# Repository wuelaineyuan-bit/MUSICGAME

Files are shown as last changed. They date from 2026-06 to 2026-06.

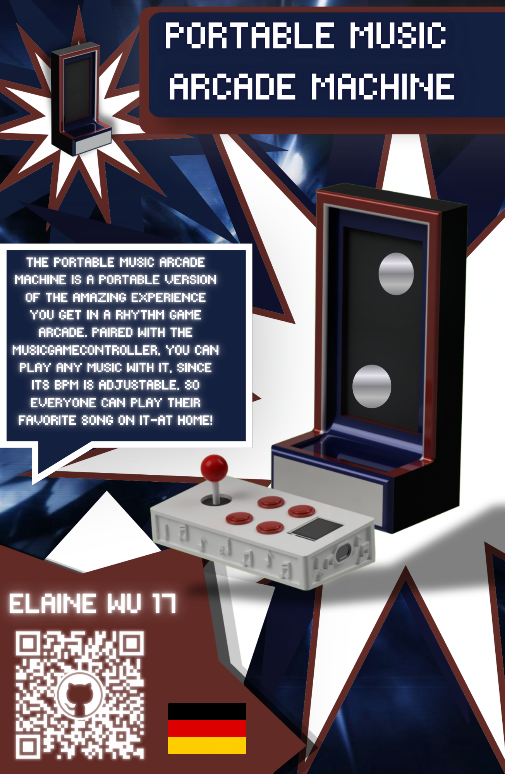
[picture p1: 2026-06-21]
zine.png

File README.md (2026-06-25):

# ARCADE-MUSICGAME
 # Zine
 zine

# Description
The music game arcade is a portable version of the amazing experience you get in a rhythm game arcade. Combined with the Music-Game-Controller, you can play any music with it, since its BPM is adjustable, so everyone can play their favorite song on it-AT HOME!

The controller itself was designed seperately in another sub project.

Musicgame-Controller: https://github.com/Gnoled5660/Musicgame-Controller
# Game Concept
Since this is my first hardware project ever, I wanted the concept to be as simple as possible, I do have quite some of software experience though. The LED Matrix as display shows two tiles (L and R) dropping down, similarly to Piano Tiles. Using the Musicgame-Controller, the player can press L, R or both at the same time in order to hit the notes. 
You can adjust BPM and the amount of beats. The higher the BPM, the harder it will be to hit the notes at the right time. The higher the amount of beats, the longer the session will be. You could even double the amount of beats if you want to play your song on loop multiple times. You need to search up the BPM and find the beatamount for your song separately.
There are four different feedbacks you can get: miss, good, great and perfect. In ascending order, they give you a higher score. The game outputs the percentage of right moves you did and also a score. Your goal is to hit the highest percentage/score. Have fun!
# Motivation
I have always loved going to music arcades. They are colorful, fun and beautiful. Most importantly, I love rhythm games. This is why I wanted to make a rhythm game with the display being an arcade controller. Originally, my idea was to use slippers as the buttons. However after my friend showed me a design, I immediately thought that the arcade controller would be alot cooler and more fitting to the theme.
There is one problem. I live in Germany and there is not a single music game arcade that I can go to and have fun with my friends. Another problem that I found was that you cant particularly choose your music. You always have to hope for songs that you like to appear magically.
With this portable music arcade game I want to bring everyone who owns it the joy of arcade games at home. Everyone in Germany, anyone in any country. And no more gambling with songs as well. Since BPM and beat amount are adjustable, you can simply search up the bpm and beat amount of your song and start playing any song, no matter how niche it might be. 
I hope this little device can light up the mood of anyone who feels a little down, just like music arcade lit me up with joy. 

# Schematic
The schematic is rather simple. The LED Matrix is powered by a Meanwell LRS-50-5, which delivers 5V and up to 10A, which is enough for the display. The Pico 2 can either be powered by the Meanwell or be connected to the computer. The only thing that is important is, that the computer needs to be connected to the Pico 2, to send over the data. However, it is also connected to the powersupply. For this reason, the Meannwell is connected to the VSYS pin of the Pico 2, with a shottkey diode in between. The Meanwell is connected to a power outlet with a cable.

Bildschirmfoto 2026-06-21 um 00 57 17

# Firmware
The Firmware was first written as normal computer program in c++, with the intention of implementing it into hardware later on. So before that, the Windows library-included command GetAsyncKeyState was used to sense input. The software itself counts the beats using the included chrono library in c++.
The software itself uses the amount of beats(beatamount), the beats per minute(bpm) and the count of the last beat (lastBeat) for the metronome/time-counting system to work and four vectors are used for the rhythm game judging system to work. 

The time-counting system works through a loop that will only run while the actual number of beats in the system is smaller than beatamount. A timestamp is also made at the start(start) of the program. This timestamp(start) is constantly getting compared to the timestamp that is created newly everytime the loop starts a new time (new). These two timestamps are used to create a duration called ms (now-start). Ms is getting compared to lastBeat as well as the amount of ms that elapse per beat (beatDMs). This procedure enables a timing system.
The judging system consists of four vectors: jubeatmap, rkeyinput, lkeyinput and accuracy. jubeatmap generates a vector that is as long as the amount of beats with randomly generated numbers from 0-3. 0 representing no beads, 1 representing one left bead, 2 representing one right bead and 3 both at the same time. These beads get rendered and sent to the matrix. r and l keyinput track the players input and after compared to jubeatmap, both get an output to the accuracy vector and output okayer feedback and also a score.

To represent this visually, I programmed the the Matrix which should be connected to the Raspberry Pi Pico. To do that I used GP2-GP7 of the Pico for the RGB of the Matrix and GP8-GP11 for ABCD, GP12-14 for CLK, LAT and OE. The PC sends DE, AD, BE and EF at the speed of +2048 per frame with one byte, eight colors and thr order being y*64+y. The judging line was at 26, The left "racing line" at 4 and the right at 36, both at 24. I wanted there to be 4 beads to be visible at the same time. 

The input comes from the seperate Musicgame-Controller(linked in description). I mapped the tokens from main.py. Before, I programmed with GetAsyncKeystate LEFT and RIGHT. I replaced them with BUTTON1 and BUTTON2. However a similar problem could occur, similar to what I have encountered with my key: so the debouncing was already fixed pretty much with a 120ms debounce. The brightness can be adjusted with BRIGHT_US, which can be different dependint on individual needs.

To run the program, simply enter BPM and amount of beats. And the game should start. 

# Assembling and Wiring
The Meanwell power supply is connected to the power outlet. And it distrubutes the power to the Pico 2 and the LED Matrix. The Pin connections can be seen below. The Pico2 is connected with the computer so that it can work.  The GP2-GP7 of the Pico should be connected to the RGB of the Matrix and GP8-GP11 for ABCD, GP12-14 for CLK, LAT and OE, as shown. You will need a 5V power supply for the matrix in order for the LEDs to work.

Bildschirmfoto 2026-06-21 um 01 07 34

# CAD Assembly
There are screw holes for the display to be mounted onto the case. The case has intentionally a hole in the back, so that the cables can reach the other components. To mount the display, you need long M4 screws. As the arcade game is going to stand next to a wall, you won't see the holes anyway. Four heat threaded inserts are needed to place them into the main CAD file, where the backplate will be mounted.

Bildschirmfoto 2026-06-21 um 01 16 15

Bildschirmfoto 2026-06-25 um 02 01 26

The CAD model consists of two major parts. One being the main case and another backplate, that can be taken off. Inside you can place the power supply unit and the Pico 2. The backplate can be detached or assembled by screwing screws through the backplate into the main case or descrewing it out.

Bildschirmfoto 2026-06-25 um 02 03 57

Bildschirmfoto 2026-06-25 um 02 03 09

This is the final finished model:



# Planning PowerPoint
Fallout is my first hardware project ever and I am very grateful, because it has such a cool concept and community. This is why I wanted to dedicate myself more to the software and details of programming while understanding the connection and bridge that overlaps the worlds of hardware and software.
This is a PowerPoint I made for myself to code my rhythm game. Since I am very inexperienced and I am doing a project like this for the first time, I decided to plan out the code and the matching hardware, before starting. This was one of the best decisions, because I did not choose to follow one of the tutorials. Maybe I should have, both have their pros and cons. At the end of the day however, I am glad that I chose the exploring route, since I have learned so much and I really did not expect to. 
Inside the PowerPoint you can see that I started with the code and its components. For this I collected all the data from a very good youtube vide, explaining each component of a rhythm game, for example the metronome or the composer. 



After this I thought about what hardware to use and I also put every single piece of data into the sheets. This was extermely useful also while creating the Fusion model since I already had the width and height.



During the coding I also put down notes. It is a habit I have always had: I would take a screenshot of some free space anywhere on the desktop and then use the snippet tool to draw on it and sort my thoughts. I ended up with quite a bit of thoughts:



[arcademusicgameforgithub.pptx](https://github.com/user-attachments/files/29168822/arcademusicgameforgithub.pptx)

# BOM
|Name |Description |Links |Quantity|Cost  |
|---|---|---|---|---|
|Raspberry Pi Pico 2|Main Microcontroller |https://www.reichelt.de/de/de/shop/produkt/raspberry_pi_pico_2_rp235x_cortex-m33_microusb-383358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 |1 |5.62  |
|LED Matrix |64x32 RGB LED |https://www.berrybase.de/64x32-rgb-led-matrix-4mm-raster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 |1 |45.78 |
|MP012801 | Cable for Display Signal connection| https://fr.farnell.com/multicomp-pro/mp012801/cordon-10p-idc-fem-fem-250mm/dp/4243695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 | 2 | 4 |
|4 pin JST-XH | Power cables for Display | https://www.amazon.fr/JST-XH-rallonges-Silicone-pour-Batterie/dp/B07Q29TG24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 | 5 | 8.4  |
|LRS-50-5 |Meanwell Power Supply |https://www.amazon.de/Mean-Well-LRS-50-5-Schaltnetzteil-Ausgang/dp/B07C8S8XR2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 |1 |15.95 |
|M4 screws |M4 x 40mm to mount Matrix |https://www.amazon.de/Schrauben-Flachkopfschrauben-Innensechskant-Edelstahl-Vollgewinde/dp/B0FBRG8CY8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|1 |4.59  |
|M3 screws | M3 x 30mm to mount back plate | https://www.aquatuning.com/fr/rrefroidissement-par-eau/personnalise/radiateurs/accessoires-pour-radiateurs/vis-m3-x-30mm-tete-fraisee-4-pieces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 | 4 | 1.7  |
|M3 threaded inserts| M3 | https://www.dold-mechatronik.de/Thread-Inserts-M3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 | 4 | 1 |
|Cable | Cable for Meanwell | https://www.reichelt.de/de/de/shop/produkt/netzkabel_schutzkontaktstecker_1_5m_schw_offenes_ende-13486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 | 1 | 4 |
|1N5817 | Shottkey diode | https://www.mouser.de/ProductDetail/Vishay-Semiconductors/1N5817-E3-54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 |1 | 0.82 |
|Filament |about 1.5kg | |1 |18 |
|total | | | |109.86|

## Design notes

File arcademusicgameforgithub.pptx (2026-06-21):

## RHYTHMGAME

## APPROACH

- Get principle
- Find physical components
- Make circuit
- Write code
- Assign code to the hardware
- Make 3d model
- (Build irl)

## COMPONENTS OF A RHYTHM GAME Software-ddd

- (Adjusting Margin: -+80ms)
- Player Input: buttonpressed 4 buttons
- ONLY ONCE PER MARGIN: IS HIT?
- 0:none
- 1: 1 button- 1 time randomly select
- … 4: 4 buttons- 4 time randomly select
- Music Player: plays tracks, switches tracks, dynamics of music, layers music/sfx
  - Indicates timeposition!==bpm
  - Wwise, fmod
- Metronome: Input bpbeat %4, bar%16, part depends STEADYCLOCK
  - Where are we?
  - m, make beatDurationSec=60/bpm (1/8 note), beatDurationMs= 60/bpm *1000, lastBeat equals 0
  - Import timepostion from the Music Player and compare it to beatDurationMs: if timepostion>=beatDurationMs
    - lastBeat++
    - Emit(„beat“, lastBeat)
    - Timeposition +=beatDurationMs
  - Error Margin (door)
    - activeBeat start/end = beatDurationMs +- margin

## COMPONENTS OF A RHYTHM GAME Software-ddd 2

- Composer
  - Writes chart based off of MIDI/bpm and set/randomized
  - Next required input: button+beat ex: A3 or K4
  - Beatx4 randomized 0(none),1(L),2(R),3(both)
  - array
- Judge HIGHRESCLOCK
  - Composer: required input?
  - Player Input: Button right?
  - Metronome: Error Margin open? Beat correct?
  - Output: yes or no
  - Perfect 20 3, great 30 2, good 50 1, miss 100ms 0
  - Using 3 vectors NOT lists: each´beatposition 3 (4)values:
  - (Beatposition), required keys, pressed keys, accuracy
- Referee (Manager) Start: Musicplayerstart, givebpmtometronome, givelvldatacomposer, EVERYONEGAMESTART
  - score
  - DisplayGame: Score according to judge
  - End: Music Player-MusicEnd,EVERYONEGAMESTOP,give final
  - Read chart of everyone – give visual feedback

## DISPLAY HW

- LED Matrix
  - 64x32 RGB LED Matrix - 3mm pitch: https://www.adafruit.com/product/2279
        - Dimensions: 191mm x 96mm x 15mm / 7.5” x 3.8” x 0.6”
        - Panel weight with IDC cables and power cables: 189g
        - Compatible with M3 mounting screws
        - 5V regulated power input @ ~4A (with all LEDs on)
        - 2000 mcd LEDs on 3mm pitch
        - 1/16 scan rate
        - Indoor display, wide visibility
        - Displays are 'chainable
  - Adafruit RGB Matrix Bonnet for Raspberry Pi: https://www.adafruit.com/product/3211
  - Power
    - 5V 4A (4000mA) switching power supply - UL Listed: https://www.adafruit.com/product/1466
    - Female DC Power adapter - 2.1mm jack to screw terminal block: https://www.adafruit.com/product/368
  - Connection
    - Adafruit RGB Matrix Bonnet for Raspberry Pi: https://www.adafruit.com/product/3211
    - to calculate the power, multiply the width of all the chained matrices * 0.12 Amps : A 32 pixel wide matrix can end up drawing 32*0.12 = 3.85A

## PROCESSOR HW

- Raspberry Pi:Model A, B, 2345 https://www.adafruit.com/categories/176
  - Depending on Code GB
  - C++ setup: https://www.raspberrypi.com/documentation/microcontrollers/c_sdk.html

## Raspberry Pi

## Error margin

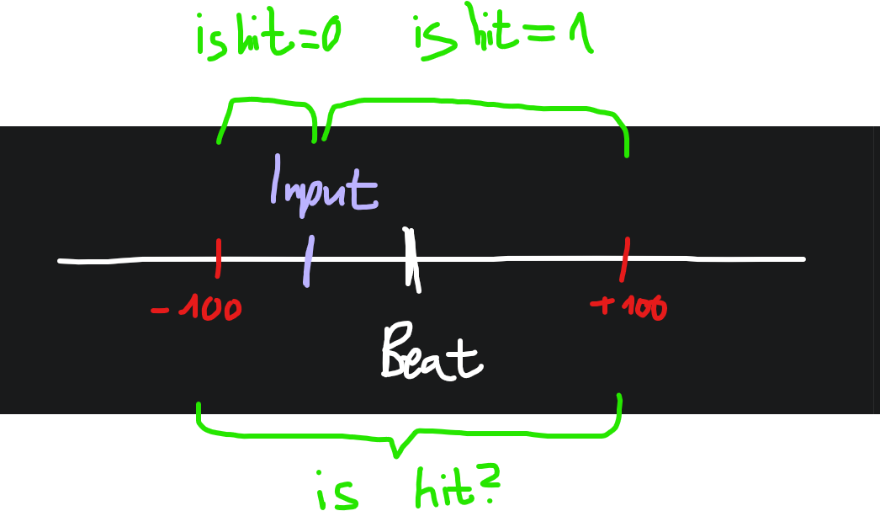
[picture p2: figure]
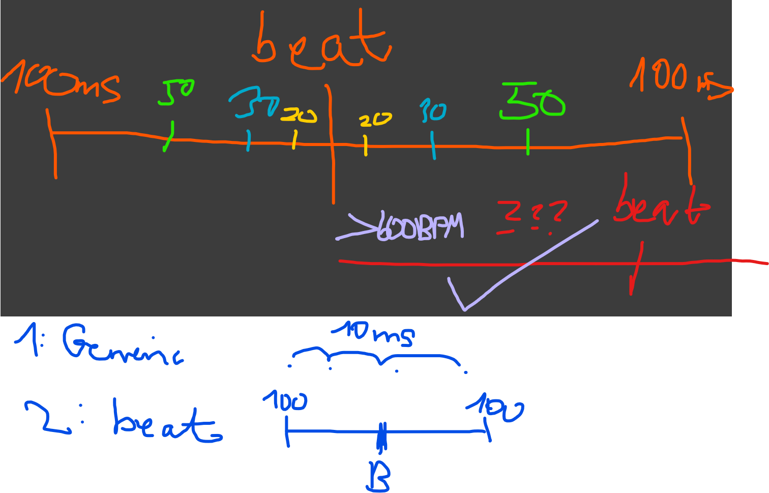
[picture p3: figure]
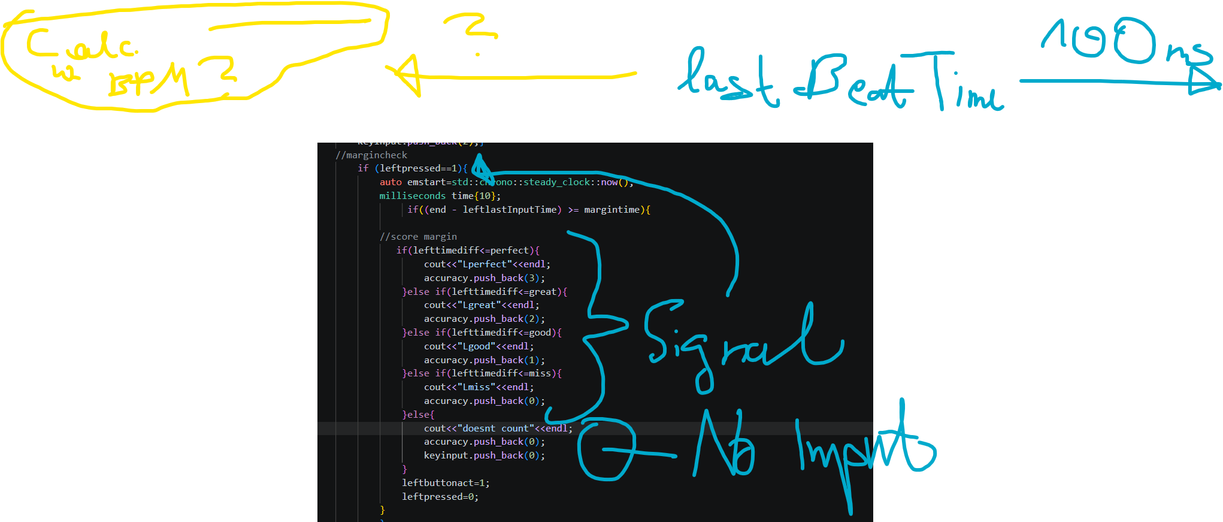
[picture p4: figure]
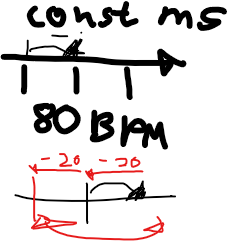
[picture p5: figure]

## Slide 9

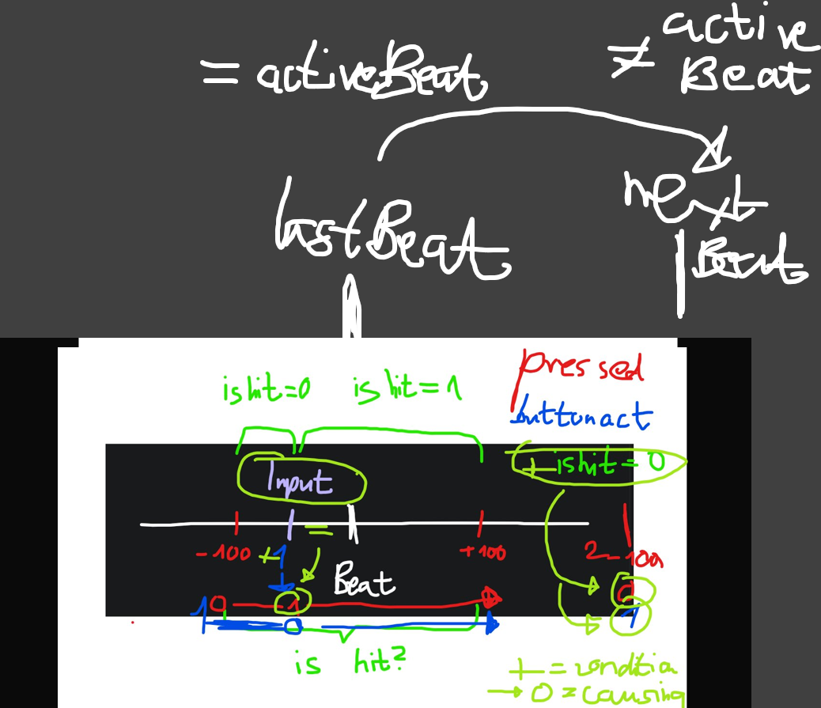
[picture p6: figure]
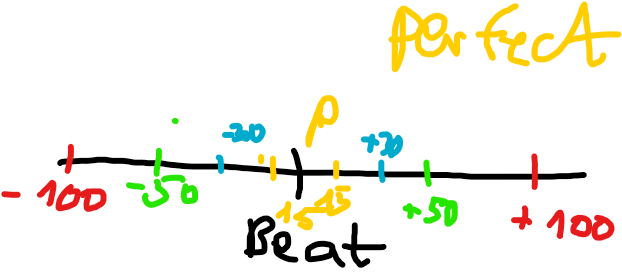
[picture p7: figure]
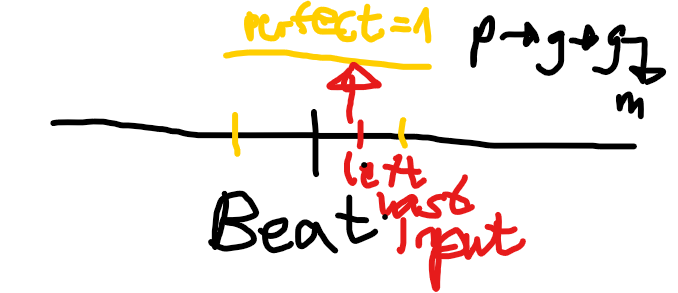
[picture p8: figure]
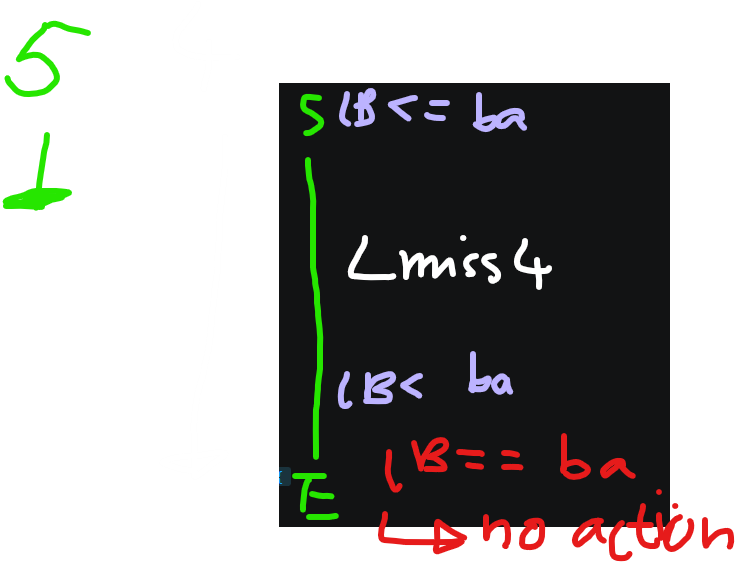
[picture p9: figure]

## First ideas

- Rhythm game: (Multiplayer) EXERCISE TOGETHER WHILE HAVING FUN!
- FNF type game on device with STOMPERS L and R
- Arcade gamed Model
- FNF game:
- Input a BPM & Difficulty
- LED matrix
- Microcontroller
- Gives SCORE
- Display https://www.adafruit.com/product/4311
- Animal slippers you have to sit down
- Senses the FNF
- sensors
- Stompers: light up lol
- LED stripes
- Hand controller:
- Senses the FNF
- Sensors
- ESP 32 MODEL: ??

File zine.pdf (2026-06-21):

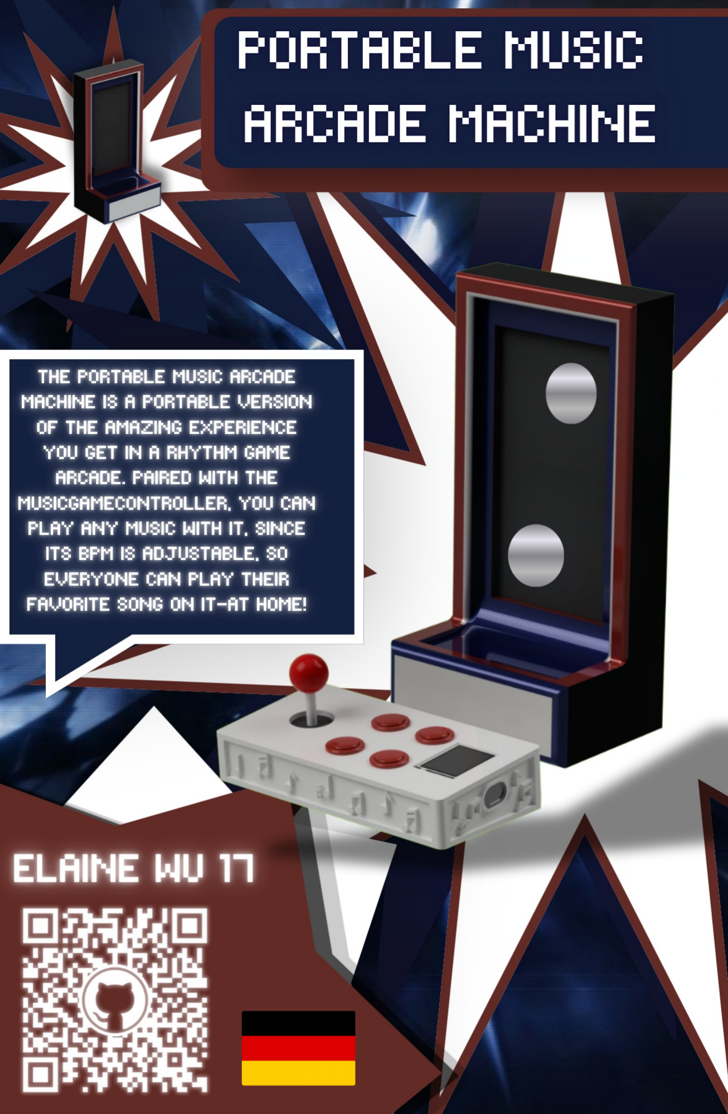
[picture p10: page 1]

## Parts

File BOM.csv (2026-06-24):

Name | Description | Links | Quantity | Cost
Raspberry Pi Pico 2 | Main Microcontroller | https://www.reichelt.de/de/de/shop/produkt/raspberry_pi_pico_2_rp235x_cortex-m33_microusb-383358?PROVID=2788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 | 1 | 5.62
LED Matrix | 64x32 RGB LED | https://www.berrybase.de/64x32-rgb-led-matrix-4mm-raster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 | 1 | 45.78
MP012801 | Cable for Display Signal connection | https://fr.farnell.com/multicomp-pro/mp012801/cordon-10p-idc-fem-fem-250mm/dp/4243695?gross_price=true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 | 2 | 4
4 pin JST-XH | Power cables for Display | https://www.amazon.fr/JST-XH-rallonges-Silicone-pour-Batterie/dp/B07Q29TG24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 | 5 | 8.4
LRS-50-5 | Meanwell Power Supply | https://www.amazon.de/Mean-Well-LRS-50-5-Schaltnetzteil-Ausgang/dp/B07C8S8XR2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 | 1 | 15.95
M4 screws | M4 x 40mm to mount Matrix | https://www.amazon.de/Schrauben-Flachkopfschrauben-Innensechskant-Edelstahl-Vollgewinde/dp/B0FBRG8CY8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 | 1 | 4.59
M3 screws | M3 x 30mm to mount back plate | https://www.aquatuning.com/fr/rrefroidissement-par-eau/personnalise/radiateurs/accessoires-pour-radiateurs/vis-m3-x-30mm-tete-fraisee-4-pieces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 | 4 | 1.7
M3 threaded inserts | M3 | https://www.dold-mechatronik.de/Thread-Inserts-M3 | 4 | 1
Cable | Cable for Meanwell | https://www.reichelt.de/de/de/shop/produkt/netzkabel_schutzkontaktstecker_1_5m_schw_offenes_ende-13486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 | 1 | 4
1N5817 | Shottkey diode | https://www.mouser.de/ProductDetail/Vishay-Semiconductors/1N5817-E3-54?qs=7w0fSgRKp91XBC3hZ6oJHw%3D%3D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 | 1 | 0.82
Filament | about 1.5kg |  | 1 | 18
total |  |  |  | 109.86

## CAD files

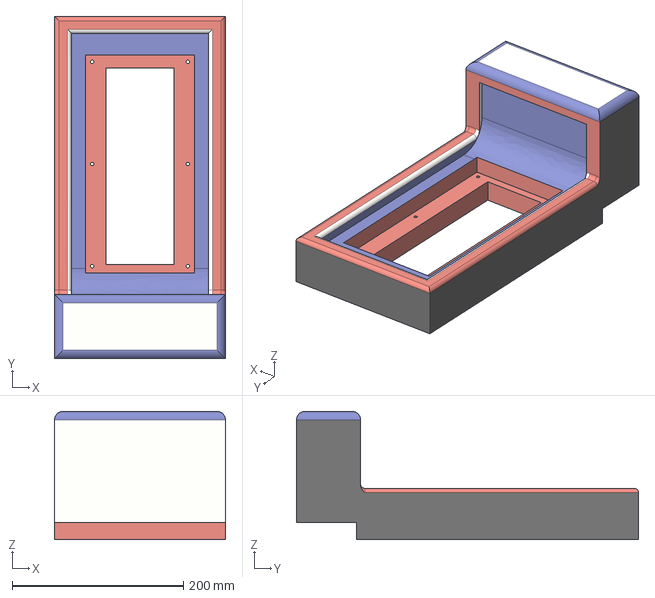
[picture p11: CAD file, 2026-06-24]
CAD/arcade display main.step
200.0 x 400.0 x 150.0 mm

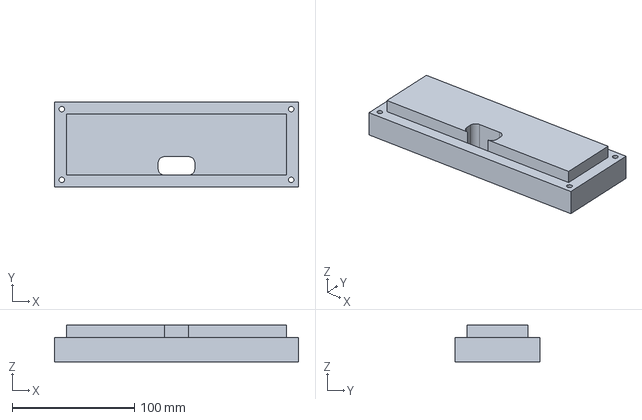
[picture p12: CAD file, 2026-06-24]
CAD/backplate arcade.step
200.0 x 70.0 x 30.0 mm

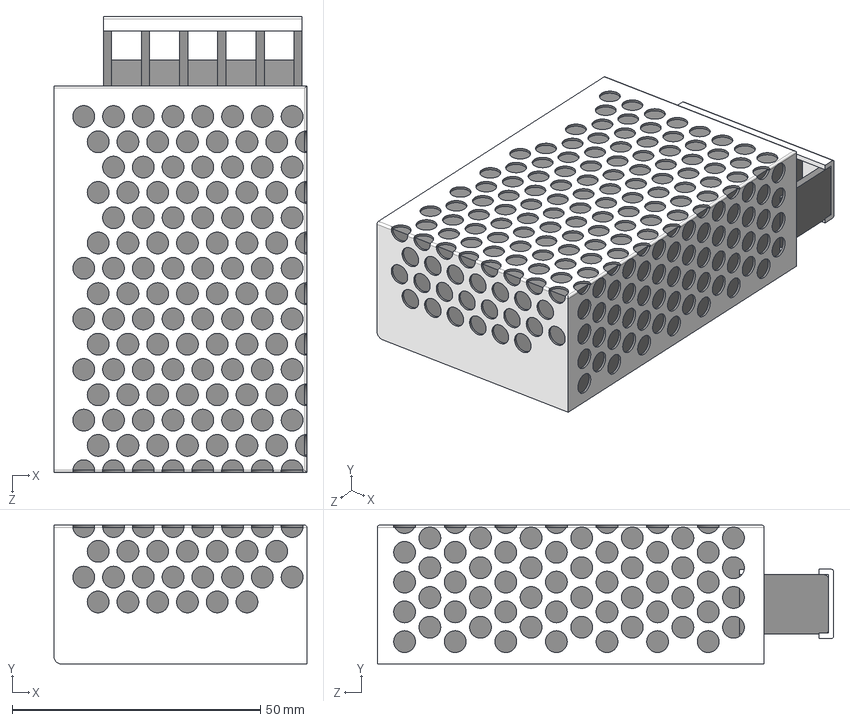
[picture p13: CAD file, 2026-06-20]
CAD/LRS-50-5.STEP
51.0 x 28.0 x 92.0 mm
PS RS-25
PS Shield

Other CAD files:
CAD/2278 RGB matrix 4mm.f3d

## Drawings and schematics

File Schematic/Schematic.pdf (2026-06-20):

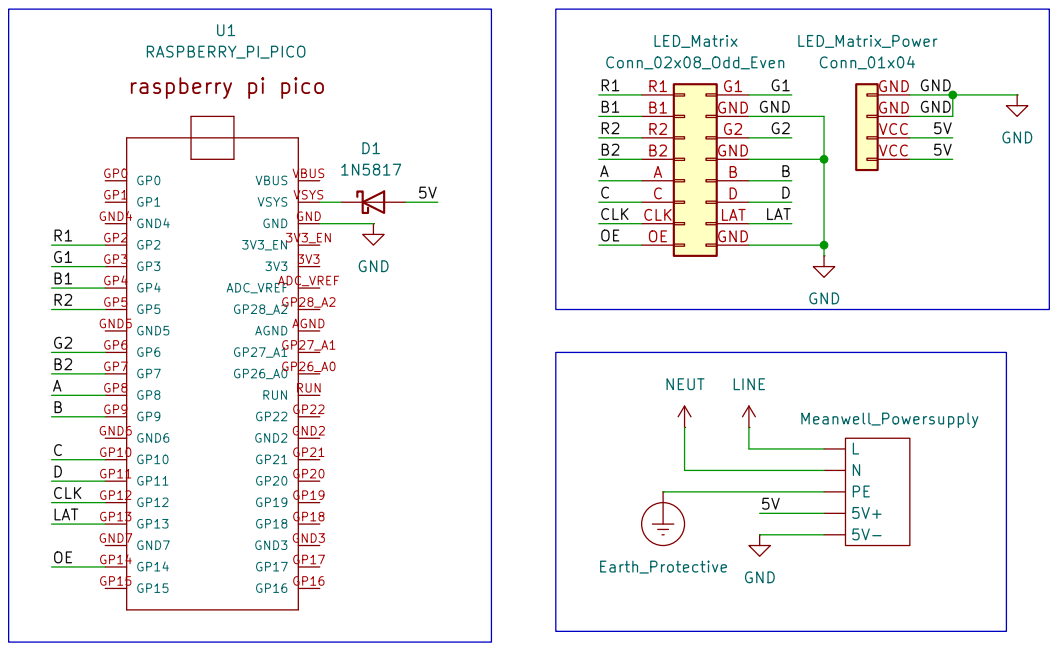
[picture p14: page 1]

Size: A4 | Rev:
KiCad E.D.A. 10.0.3 | Id: 1/1

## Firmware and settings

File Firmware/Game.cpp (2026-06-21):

#include <iostream>
#include <thread>
#include <chrono>
#include <ctime>
#include <cstdlib>
#include <cstring>
#include <cstdint>
#include <vector>
#include <cmath>
#include <string>

#ifdef _WIN32
  #include <windows.h>
#else
  #include <fcntl.h>
  #include <termios.h>
  #include <unistd.h>
  #include <errno.h>
#endif

using namespace std::chrono;
using namespace std;

class Serial {
public:
    bool open(const string& port, int baud);
    void close();
    int  readBytes(uint8_t* buf, int maxlen);   
    int  writeBytes(const uint8_t* buf, int len);
    bool isOpen() const { return open_; }
private:
    bool open_ = false;
#ifdef _WIN32
    HANDLE h_ = INVALID_HANDLE_VALUE;
#else
    int fd_ = -1;
#endif
};

#ifndef _WIN32
bool Serial::open(const string& port, int baud) {
    fd_ = ::open(port.c_str(), O_RDWR | O_NOCTTY | O_NONBLOCK);
    if (fd_ < 0) { perror(("open " + port).c_str()); return false; }
    termios tio{};
    if (tcgetattr(fd_, &tio) != 0) { perror("tcgetattr"); ::close(fd_); fd_ = -1; return false; }
    cfmakeraw(&tio);
    speed_t spd = B115200;
    switch (baud) {
        case 9600:   spd = B9600;   break;
        case 115200: spd = B115200; break;
        case 230400: spd = B230400; break;
#ifdef B460800
        case 460800: spd = B460800; break;
#endif
#ifdef B921600
        case 921600: spd = B921600; break;
#endif
        default: spd = B115200; break;
    }
    cfsetispeed(&tio, spd);
    cfsetospeed(&tio, spd);
    tio.c_cflag |= (CLOCAL | CREAD);
    tio.c_cflag &= ~CRTSCTS;
    tio.c_cc[VMIN]  = 0;  
    tio.c_cc[VTIME] = 0;
    if (tcsetattr(fd_, TCSANOW, &tio) != 0) { perror("tcsetattr"); ::close(fd_); fd_ = -1; return false; }
    open_ = true;
    return true;
}
void Serial::close() { if (fd_ >= 0) ::close(fd_); fd_ = -1; open_ = false; }
int Serial::readBytes(uint8_t* buf, int maxlen) {
    if (fd_ < 0) return -1;
    int n = ::read(fd_, buf, maxlen);
    if (n < 0) { if (errno == EAGAIN || errno == EWOULDBLOCK) return 0; return -1; }
    return n;
}
int Serial::writeBytes(const uint8_t* buf, int len) {
    if (fd_ < 0) return -1;
    int n = ::write(fd_, buf, len);
    if (n < 0) { if (errno == EAGAIN || errno == EWOULDBLOCK) return 0; return -1; }
    return n;
}
#else  
bool Serial::open(const string& port, int baud) {
    string full = "\\\\.\\" + port;               
    h_ = CreateFileA(full.c_str(), GENERIC_READ | GENERIC_WRITE, 0, NULL, OPEN_EXISTING, 0, NULL);
    if (h_ == INVALID_HANDLE_VALUE) { cerr << "open " << port << " failed\n"; return false; }
    DCB dcb{}; dcb.DCBlength = sizeof(dcb);
    GetCommState(h_, &dcb);
    dcb.BaudRate = baud; dcb.ByteSize = 8; dcb.Parity = NOPARITY; dcb.StopBits = ONESTOPBIT;
    dcb.fBinary = TRUE; dcb.fDtrControl = DTR_CONTROL_ENABLE; dcb.fRtsControl = RTS_CONTROL_ENABLE;
    SetCommState(h_, &dcb);
    COMMTIMEOUTS to{};
    to.ReadIntervalTimeout = MAXDWORD;            
    to.ReadTotalTimeoutConstant = 0; to.ReadTotalTimeoutMultiplier = 0;
    to.WriteTotalTimeoutConstant = 50; to.WriteTotalTimeoutMultiplier = 0;
    SetCommTimeouts(h_, &to);
    open_ = true; return true;
}
void Serial::close() { if (h_ != INVALID_HANDLE_VALUE) CloseHandle(h_); h_ = INVALID_HANDLE_VALUE; open_ = false; }
int Serial::readBytes(uint8_t* buf, int maxlen) {
    if (h_ == INVALID_HANDLE_VALUE) return -1;
    DWORD got = 0; if (!ReadFile(h_, buf, maxlen, &got, NULL)) return -1; return (int)got;
}
int Serial::writeBytes(const uint8_t* buf, int len) {
    if (h_ == INVALID_HANDLE_VALUE) return -1;
    DWORD wr = 0; if (!WriteFile(h_, buf, len, &wr, NULL)) return -1; return (int)wr;
}
#endif

string cstart      = "a";
int    beatamount  = 0;
int    bpm         = 1;
int    lastBar     = 1;

int  lastBeat   = 0;
int  activeBeat = -1;
bool beatJudged = false;

bool leftpressed    = false;
bool rightpressed   = false;
bool leftbuttonact  = true;
bool rightbuttonact = true;

vector<int> jubeatmap;
vector<int> rkeyinput;
vector<int> lkeyinput;
vector<int> accuracy;

auto leftlastInputTime  = steady_clock::now();
auto rightlastInputTime = steady_clock::now();
auto lastBeatTime       = steady_clock::now();

static const int MW = 64, MH = 32;
static uint8_t fb[MH * MW];

enum {
    C_OFF = 0, C_RED = 1, C_GREEN = 2, C_YEL = 3,   // R=1,G=2,R|G=3
    C_BLUE = 4, C_MAG = 5, C_CYAN = 6, C_WHITE = 7  // B=4,R|B=5,G|B=6,R|G|B=7
};

inline void px(int x, int y, uint8_t c) {
    if (x >= 0 && x < MW && y >= 0 && y < MH) fb[y * MW + x] = c;
}
inline void fillRect(int x, int y, int w, int h, uint8_t c) {
    for (int j = 0; j < h; j++)
        for (int i = 0; i < w; i++) px(x + i, y + j, c);
}
inline void clearFB() { memset(fb, 0, sizeof(fb)); }

static const uint8_t MAGIC[4] = { 0xDE, 0xAD, 0xBE, 0xEF };

void sendFrame(Serial& s) {
    if (!s.isOpen()) return;
    static uint8_t packet[4 + MH * MW];
    memcpy(packet, MAGIC, 4);
    memcpy(packet + 4, fb, MH * MW);

    s.writeBytes(packet, sizeof(packet));
}

static const int    JUDGE_Y         = 26;  
static const int    NOTE_H          = 3;
static const double LOOKAHEAD_BEATS = 4.0;   
static const int    L_X = 4,  L_W = 24;      
static const int    R_X = 36, R_W = 24;      

struct Flash { long long t0 = -1; int lanes = 0; uint8_t color = 0; };
Flash flash;

uint8_t accColor(int r) {                    // 3=perfect 2=great 1=good 0=miss
    switch (r) { case 3: return C_WHITE; case 2: return C_CYAN; case 1: return C_YEL; default: return C_RED; }
}

void renderFrame(long long ms, int beatDMs) {
    clearFB();
    double pxPerBeat = (double)JUDGE_Y / LOOKAHEAD_BEATS;

    fillRect(0, JUDGE_Y, MW, 1, C_BLUE);

    for (int i = 0; i < beatamount; i++) {
        int note = jubeatmap[i];
        if (note == 0) continue;                                  // Pause = keine Note
        double dBeats = ((double)i * beatDMs - (double)ms) / (double)beatDMs;
        if (dBeats > LOOKAHEAD_BEATS || dBeats < -1.0) continue;  // ausserhalb des Sichtfelds
        int y  = (int)lround(JUDGE_Y - dBeats * pxPerBeat);
        int yy = y - NOTE_H / 2;
        if (note == 1 || note == 3) fillRect(L_X, yy, L_W, NOTE_H, C_GREEN);
        if (note == 2 || note == 3) fillRect(R_X, yy, R_W, NOTE_H, C_MAG);
    }

    if (flash.t0 >= 0 && ms - flash.t0 < 130) {
        if (flash.lanes & 1) fillRect(L_X, JUDGE_Y - 3, L_W, 6, flash.color);
        if (flash.lanes & 2) fillRect(R_X, JUDGE_Y - 3, R_W, 6, flash.color);
    }
}


struct CtrlIn {
    Serial* s = nullptr;
    string  line;
    long long lastLeftMs  = -100000;
    long long lastRightMs = -100000;
    bool leftEdge  = false;
    bool rightEdge = false;
    static const int DEBOUNCE_MS = 120;

    void pump(long long nowMs) {
        if (!s || !s->isOpen()) return;
        uint8_t buf[256];
        int n = s->readBytes(buf, sizeof(buf));
        for (int i = 0; i < n; i++) {
            char c = (char)buf[i];
            if (c == '\n' || c == '\r') {
                if (!line.empty()) { handle(line, nowMs); line.clear(); }
            } else if (line.size() < 31) {
                line.push_back(c);
            } else {
                line.clear();  
            }
        }
    }
    void handle(const string& tok, long long nowMs) {
        if (tok == "LEFT" || tok == "BUTTON1") {
            if (nowMs - lastLeftMs > DEBOUNCE_MS) leftEdge = true;
            lastLeftMs = nowMs;
        } else if (tok == "RIGHT" || tok == "BUTTON2") {
            if (nowMs - lastRightMs > DEBOUNCE_MS) rightEdge = true;
            lastRightMs = nowMs;
        }
    }
};
CtrlIn ctrl;

void getStats() {
    cout << "beatamount:" << endl;
    cin  >> beatamount;
    cout << "enter bpm:" << endl;
    cin  >> bpm;
    if (bpm <= 0) { cout << "BPM must be greater than 0" << endl; beatamount = 0; return; }
    cout << "type anything to start" << endl;
    cin  >> cstart;
    cout << lastBar << endl;
}

void composer() {
    srand((unsigned)time(0));
    jubeatmap.clear(); lkeyinput.clear(); rkeyinput.clear(); accuracy.clear();
    for (int i = 0; i < beatamount; i++) {
        int r = rand() % 4;               // 0=Pause 1=links 2=rechts 3=beide
        jubeatmap.push_back(r);
        cout << jubeatmap.back() << endl;
    }
    lkeyinput.resize(beatamount, 0);
    rkeyinput.resize(beatamount, 0);
    accuracy .resize(beatamount, 0);
}

void metronome(Serial& matrix) {
    const int beatDMs       = 60000 / bpm;
    const long long perfectWindow = 15, greatWindow = 30, goodWindow = 50, hitWindow = 100;

    auto start = steady_clock::now();
    cout << lastBar << " BAR" << endl;

    long long lastFrameMs = -1000;

    while (true) {
        auto now      = steady_clock::now();
        long long ms  = duration_cast<milliseconds>(now - start).count();

        ctrl.pump(ms);

        if (lastBeat < beatamount && ms >= (long long)lastBeat * beatDMs) {
            lastBar++;
            lastBeatTime  = now;
            activeBeat    = lastBeat;
            beatJudged    = false;
            leftpressed   = false; rightpressed  = false;
            leftbuttonact = true;  rightbuttonact = true;
            ctrl.leftEdge = false; ctrl.rightEdge = false;   // frisches Fenster

            cout << "beat:" << (lastBeat + 1) << " t:" << ms
                 << " bpm:" << bpm << " note:" << jubeatmap[lastBeat] << endl;
            if (lastBar % 4 == 0) cout << lastBar / 4 << " BAR" << endl;
            lastBeat++;
        }

        if (activeBeat >= 0 && activeBeat < beatamount && !beatJudged) {
            int noteType            = jubeatmap[activeBeat];
            long long beatTargetMs  = (long long)activeBeat * beatDMs;
            long long diffMs        = ms - beatTargetMs;

            if ((noteType == 1 || noteType == 3) && ctrl.leftEdge && leftbuttonact && !leftpressed) {
                ctrl.leftEdge = false;
                leftlastInputTime = now; leftpressed = true; leftbuttonact = false;
                cout << "Lpressed" << endl;
            }
            if ((noteType == 2 || noteType == 3) && ctrl.rightEdge && rightbuttonact && !rightpressed) {
                ctrl.rightEdge = false;
                rightlastInputTime = now; rightpressed = true; rightbuttonact = false;
                cout << "Rpressed" << endl;
            }

            bool windowClosed   = (diffMs > hitWindow);
            bool canJudgeEarly  = (noteType == 3 && leftpressed && rightpressed);
            bool canJudgeSingle = ((noteType == 1 && leftpressed) || (noteType == 2 && rightpressed));

            if (windowClosed || canJudgeEarly || canJudgeSingle) {
                beatJudged = true;

                auto judgeOffset = [&](steady_clock::time_point it) -> long long {
                    return llabs(duration_cast<milliseconds>(it - lastBeatTime).count());
                };
                auto rate = [&](long long off) -> int {
                    if (off <= perfectWindow) return 3;
                    if (off <= greatWindow)   return 2;
                    if (off <= goodWindow)    return 1;
                    return 0;
                };

                if (noteType == 0) {
                    accuracy[activeBeat] = 3; lkeyinput[activeBeat] = 1; rkeyinput[activeBeat] = 1;
                    flash = { ms, 3, C_GREEN };
                }
                else if (noteType == 1) {
                    if (leftpressed) {
                        long long off = judgeOffset(leftlastInputTime);
                        int r = rate(off);
                        accuracy[activeBeat] = r; lkeyinput[activeBeat] = (r > 0) ? 1 : 0;
                        flash = { ms, 1, accColor(r) };
                        const char* L[] = {"Lmiss","Lgood","Lgreat","Lperfect"};
                        cout << L[r] << " (off " << off << "ms)" << endl;
                    } else {
                        accuracy[activeBeat] = 0; lkeyinput[activeBeat] = 0;
                        flash = { ms, 1, C_RED };
                        cout << "Lmiss (no press)" << endl;
                    }
                }
                else if (noteType == 2) {
                    if (rightpressed) {
                        long long off = judgeOffset(rightlastInputTime);
                        int r = rate(off);
                        accuracy[activeBeat] = r; rkeyinput[activeBeat] = (r > 0) ? 1 : 0;
                        flash = { ms, 2, accColor(r) };
                        const char* L[] = {"Rmiss","Rgood","Rgreat","Rperfect"};
                        cout << L[r] << " (off " << off << "ms)" << endl;
                    } else {
                        accuracy[activeBeat] = 0; rkeyinput[activeBeat] = 0;
                        flash = { ms, 2, C_RED };
                        cout << "Rmiss (no press)" << endl;
                    }
                }
                else if (noteType == 3) {
                    if (leftpressed && rightpressed) {
                        long long lOff = judgeOffset(leftlastInputTime);
                        long long rOff = judgeOffset(rightlastInputTime);
                        int r = rate(max(lOff, rOff));
                        accuracy[activeBeat] = r;
                        lkeyinput[activeBeat] = (r > 0) ? 1 : 0;
                        rkeyinput[activeBeat] = (r > 0) ? 1 : 0;
                        flash = { ms, 3, accColor(r) };
                        const char* L[] = {"BothMiss","BothGood","BothGreat","BothPerfect"};
                        cout << L[r] << " (L " << lOff << "ms, R " << rOff << "ms)" << endl;
                    } else {
                        accuracy[activeBeat] = 0; lkeyinput[activeBeat] = 0; rkeyinput[activeBeat] = 0;
                        flash = { ms, 3, C_RED };
                        cout << "BothMiss (partial press)" << endl;
                    }
                }
            }
        }
      
        if (ms - lastFrameMs >= 33) {
            renderFrame(ms, beatDMs);
            sendFrame(matrix);
            lastFrameMs = ms;
        }

        if (lastBeat >= beatamount && beatJudged) break;
        this_thread::sleep_for(milliseconds(1));
    }
  
    long long endMs = duration_cast<milliseconds>(steady_clock::now() - start).count();
    renderFrame(endMs, beatDMs);
    sendFrame(matrix);
}

void judgecheck() {
    int score = 0;
    for (int k = 0; k < (int)jubeatmap.size(); k++) {
        if (jubeatmap[k] == 0) continue;
        bool hit = false;
        if      (jubeatmap[k] == 1) hit = (lkeyinput[k] == 1);
        else if (jubeatmap[k] == 2) hit = (rkeyinput[k] == 1);
        else if (jubeatmap[k] == 3) hit = (lkeyinput[k] == 1 && rkeyinput[k] == 1);
        if (hit) score += accuracy[k];
    }
    cout << "\n=== RESULTS ===" << endl;
    cout << "jubeatmap: "; for (int v : jubeatmap) cout << v; cout << endl;
    cout << "lkeyinput: "; for (int v : lkeyinput) cout << v; cout << endl;
    cout << "rkeyinput: "; for (int v : rkeyinput) cout << v; cout << endl;
    cout << "accuracy:  "; for (int v : accuracy)  cout << v; cout << endl;
    cout << "SCORE: " << score << endl;

    int maxScore = 0;
    for (int k = 0; k < (int)jubeatmap.size(); k++) if (jubeatmap[k] != 0) maxScore += 3;
    if (maxScore > 0)
        cout << "(" << (int)(100.0 * score / maxScore) << "% of max " << maxScore << ")" << endl;
}

int main(int argc, char** argv) {
    string ctrlPort   = "/dev/cu.usbmodem1101";   // Controller-Pico  (Eingabe)
    string matrixPort = "/dev/cu.usbmodem2101";   // Matrix-Pico      (Anzeige)
    if (argc >= 2) ctrlPort   = argv[1];
    if (argc >= 3) matrixPort = argv[2];

    Serial ctrlSerial, matrixSerial;
    if (!ctrlSerial.open(ctrlPort, 115200))
        cout << "WARN: Controller-Port nicht geoeffnet (" << ctrlPort
             << ") -> keine Eingabe, Anzeige laesst sich aber testen.\n";
    if (!matrixSerial.open(matrixPort, 115200))
        cout << "WARN: Matrix-Port nicht geoeffnet (" << matrixPort
             << ") -> keine LED-Ausgabe.\n";
    ctrl.s = &ctrlSerial;

    getStats();
    if (beatamount <= 0 || bpm <= 0) { cout << "Invalid input. Exiting." << endl; return 1; }
    composer();
    metronome(matrixSerial);
    judgecheck();

    ctrlSerial.close();
    matrixSerial.close();
    return 0;
}

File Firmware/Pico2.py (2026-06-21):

import rp2, sys, time, micropython, uselect
from machine import Pin
from array import array

WIDTH, HEIGHT = 64, 32
ROWS          = HEIGHT // 2          
WORDS_PER_ROW = WIDTH // 4           
PIO_FREQ      = 22_000_000     
BRIGHT_US     = 180                  
DRAIN_CAP     = 256                  
MAGIC         = b'\xDE\xAD\xBE\xEF'

addr_pins = [Pin(8, Pin.OUT), Pin(9, Pin.OUT), Pin(10, Pin.OUT), Pin(11, Pin.OUT)] 
lat = Pin(13, Pin.OUT, value=0)
oe  = Pin(14, Pin.OUT, value=1)      

def set_addr(r):
    addr_pins[0].value(r & 1)
    addr_pins[1].value((r >> 1) & 1)
    addr_pins[2].value((r >> 2) & 1)
    addr_pins[3].value((r >> 3) & 1)

@rp2.asm_pio(out_init=(rp2.PIO.OUT_LOW,) * 6,
             sideset_init=rp2.PIO.OUT_LOW,
             out_shiftdir=rp2.PIO.SHIFT_RIGHT,
             autopull=True, pull_thresh=24)
def hub75_data():
    out(pins, 6).side(0)  
    nop().side(1)            

sm = rp2.StateMachine(0, hub75_data, freq=PIO_FREQ,
                      out_base=Pin(2), sideset_base=Pin(12))
sm.active(1)

fb     = bytearray(WIDTH * HEIGHT)                      
rowbuf = [array('I', [0] * WORDS_PER_ROW) for _ in range(ROWS)]

def pack():
    # fb -> rowbuf: je Zeilenpaar 64 Pixel zu 16 Woertern (4 Pixel * 6 Bit = 24 Bit)
    for r in range(ROWS):
        rb  = rowbuf[r]
        top = r * WIDTH
        bot = (r + ROWS) * WIDTH
        i = 0
        for w in range(WORDS_PER_ROW):
            word = 0
            for k in range(4):
                t = fb[top + i] & 7      
                b = fb[bot + i] & 7   
                word |= (t | (b << 3)) << (k * 6)
                i += 1
            rb[w] = word

def refresh():
    for r in range(ROWS):
        sm.put(rowbuf[r])           
        while sm.tx_fifo():            
            pass
        time.sleep_us(2)              
        oe.value(1)                    
        set_addr(r)
        lat.value(1); lat.value(0)     
        oe.value(0)                    
        time.sleep_us(BRIGHT_US)

micropython.kbd_intr(-1)            
spoll = uselect.poll()
spoll.register(sys.stdin.buffer, uselect.POLLIN)

_sync  = bytearray(4)              
_state = 0                           
_plen  = 0
_payload = bytearray(WIDTH * HEIGHT)

def drain(max_bytes=DRAIN_CAP):
    # Liest verfuegbare Bytes (nicht blockierend, gedeckelt) und baut Frames auf.
    global _state, _plen
    count = 0
    while count < max_bytes and spoll.poll(0):
        b = sys.stdin.buffer.read(1)
        if not b:
            break
        count += 1
        byte = b[0]
        if _state == 0:
            _sync[0] = _sync[1]; _sync[1] = _sync[2]; _sync[2] = _sync[3]; _sync[3] = byte
            if _sync == MAGIC:
                _state = 1; _plen = 0
        else:
            _payload[_plen] = byte; _plen += 1
            if _plen >= WIDTH * HEIGHT:
                fb[:] = _payload
                pack()
                _state = 0

def selftest():
    for y in range(HEIGHT):
        for x in range(WIDTH):
            fb[y * WIDTH + x] = ((x // 8) % 7) + 1
    pack()
    t_end = time.ticks_add(time.ticks_ms(), 2000)
    while time.ticks_diff(t_end, time.ticks_ms()) > 0:
        refresh()
    for i in range(len(fb)):
        fb[i] = 0
    pack()

selftest()
while True:
    refresh()
    oe.value(1)   
    drain()

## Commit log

2026-06-20 Revise README with new sections and content
    Updated project description and added sections for game concept, planning, and BOM details.
2026-06-21 Added CAD source file
2026-06-21 Revise game concept description in README
    Clarified the game concept and simplified the explanation of the LED Matrix display and gameplay mechanics.
2026-06-21 Clean up README.md formatting and links
    Removed duplicate link to PowerPoint and fixed formatting issues.
2026-06-22 Update Pico2.py for controlling LED matrix display
2026-06-24 Create full assembly.stp
2026-06-24 Update README with program instructions and wiring info
    Added instructions to run the program and clarified wiring details.
2026-06-24 Update CAD files
    [arcade display main.step, backplate arcade.step]
2026-06-24 CAD update
